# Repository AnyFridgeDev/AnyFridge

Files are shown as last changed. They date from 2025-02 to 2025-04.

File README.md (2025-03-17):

# AnyFridge

## GitHub
[GitHub](https://github.com/AnyFridgeDev/AnyFridge)

## Authors
- [Isaac Fletcher](https://github.com/isaac-fletcher)
- [Ethan Anderson](https://github.com/Elan456)
- [Caden Allen](https://github.com/coolguycaden)

## Project Overview

This is the development repository for AnyFridge, a compact device that brings smart features to any refrigerator. No need to buy the latest expensive model!
It is a WiFi-connected UPC barcode scanner that mounts magnetically to your fridge to make keeping track of your store purchases extremely convenient. Each item you scan will be cataloged in a web app that lets you view and manage your inventory levels.

## Organization

This repository is organized into the following sections:
    
    hardware/ - Stores system schematics and PCB for custom system hardware
        
        libraries/ - Stores custom libraries containing custom components in the schematics
    
    software/ - Contains custom firmware written for the ESP32
        
    webapp/ - Contains Python web app to handle inventory tracking management
    
    docs/ - Stores documentation about the project hardware and software

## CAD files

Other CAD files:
design/sleeve.blend

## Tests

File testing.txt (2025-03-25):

---Team Members---

Ethan Anderson (ema8@clemson.edu)
Isaac Fletcher (ifletch@clemson.edu)
Caden Allen (caden3@clemson.edu)

[GitHub](https://github.com/AnyFridgeDev/AnyFridge)

----AnyFridge Testing Guide---- 

Our tests are broken into two main categories
1. Onboard Software
2. Web App and Request Handling

Below our instructions and explanations for each test for each of the
two main categories.

---Onboard Software Tests---

For our onboard software, we use PlatformIO (PIO) to build and upload our code.
It's typically used as an extension for VS Code. 
To run our tests, you can use the CLI version which can be 
installed here: https://platformio.org/install 

--Test Barcode-- 

The barcode test ensures that we are able to scan UPC barcodes accurately.
The test starts by running a few unit test to ensure a good serial connection to
the barcode scanner. The test then enters a loop where it constantly scans and
prints any codes that are read to the serial monitor. 

Instructions:
1. Connect the barcode scanner using a breadboard
	(ESP32 pin) = (Scanner pin)
  	2 			= 	TX pin on scanner
  	3 			= 	RX pin on scanner
  	GND			= 	GND
  	3.3V 		= 	3.3V
2. cd into the software directory
	`cd software`
3. Run the test
	`pio test -f test_barcode`

--Test WiFi--

The WiFi test connects to a hard-coded WiFi network and then checks that
google.com can be pinged successfully.
It also tests sending a GET request to a custom domain of af.ethananderson.dev
where we have a server running to show what contents it receives. 
This test allows to check the WiFi functionality of the board. 

Instructions: 
1. cd into the software directory
	`cd software`
2. Edit the WiFi name and network passwords
	`vim test_wifi/test_wifi.cpp`
	Change `networkName` and `networkPswd` (smart phone hotspots work really well)
3. Run the test
	`pio test -f test_wifi`

--Test Access Point--

During the setup phase of the device, the user needs to be able to connect to
AnyFridge and give it network details to connect with.
The access point test puts the ESP32 into AP mode and then checks if 
it got an IP address.

Instructions:
1. cd into the software directory
	`cd software`
2. Run the test
	`pio test -f test_ap` 

If all the tests pass, it means the ESP32 went into AP mode and got an IP 
address on it's own local network. 

---Web App and Request Handling Tests---

Navigate to the `AnyFridge/webapp` folder.

The webapp processes code scans sent from the AnyFridge device. 
The webapp updates each user's list of scanned items based on the code 
and user id sent by the AnyFridge device. 

--Download Depdencies--

Before running the webapp, we'll need to install some Python packages. 

`cd webapp`
`pip install -r requirements.txt `

--Test Request Handling--

The AnyFridge device will send requests to the request handling server,
so we wrote tests that emulate each of these requests to ensure our server
handles them properly.

We check two main endpoints:
1. /api/update
Should change the list of scanned codes for the provided user.

2. /api/get/<userid>
Should return a list of all scanned codes for the provided user.

The test uses a FastAPI's built-in TestClient to simulate the request and
their handling. 

Instructions:
1. Run the command: `python -m unittest tests/test_request_handling.py`

If all the tests pass, it means the server succesfully updated and then 
later collected the expected scan lists for each user. 

--Local cURL + frontend check--

Another test involves hosting the webapp locally, sending a POST request to it 
and then viewing the website to ensure the scan list was updated properly. 

Instructions:
1. cd into the `AnyFridge/webapp` directory 
2. Run the curl command with `sh tests/local_curl_check.sh <userid>`
	Put whatever you like for the userid.
3. View the website and see if Frosted brown sugar cinnamon pastries 
are shown in the list. 

If everything worked, you'll also see a json file created inside of the 
`AnyFridge/webapp/data` folder named <userid>.json. It should contain the
upc code of the pastries. 

---Integration Test--
Navigate to the `AnyFridge/` folder.

--Test System Integration--
A sample program has been provided to test the scanning, WiFi, and web request
components of the device. It is to be used in conjunction with the 
request handler and gradio test ui to confirm that codes are being appropriately 
scanned and sent over the network.

Instructions:
1. Edit the WiFi name, network passwords, and host address
	`vim software/test/test_integration/test_integration.cpp`
	Change `networkName` and `networkPswd` (smart phone hotspots work really well)
    Change `host` to point to designated machine on the same network that will
	serve request handler and UI. You'll need to get the ip address of this machine
	on your hotspot network. 
2. cd into the webapp directory: `cd webapp`
3. Start the request handler on designated machine: `python request_handler.py`
4. Open another terminal 
4. Start the gradio debugging UI on designated machine: `gradio gradio_ui.py`
5. Open another terminal 
5. cd into the software directory: `cd software`
4. Upload and run the code onto the AnyFridge device. 
	`pio test -f test_integration` 
5. Scan a UPC code with the barcode scanner within 10 seconds 
6. Open the following page and type in "test_user" as the user_id. 
	http://0.0.0.0:8080

If everthing is working, when you scan a UPC code, you'll see the 
code printed to the serial monitor and the item appear on the locally-hosted 
website.

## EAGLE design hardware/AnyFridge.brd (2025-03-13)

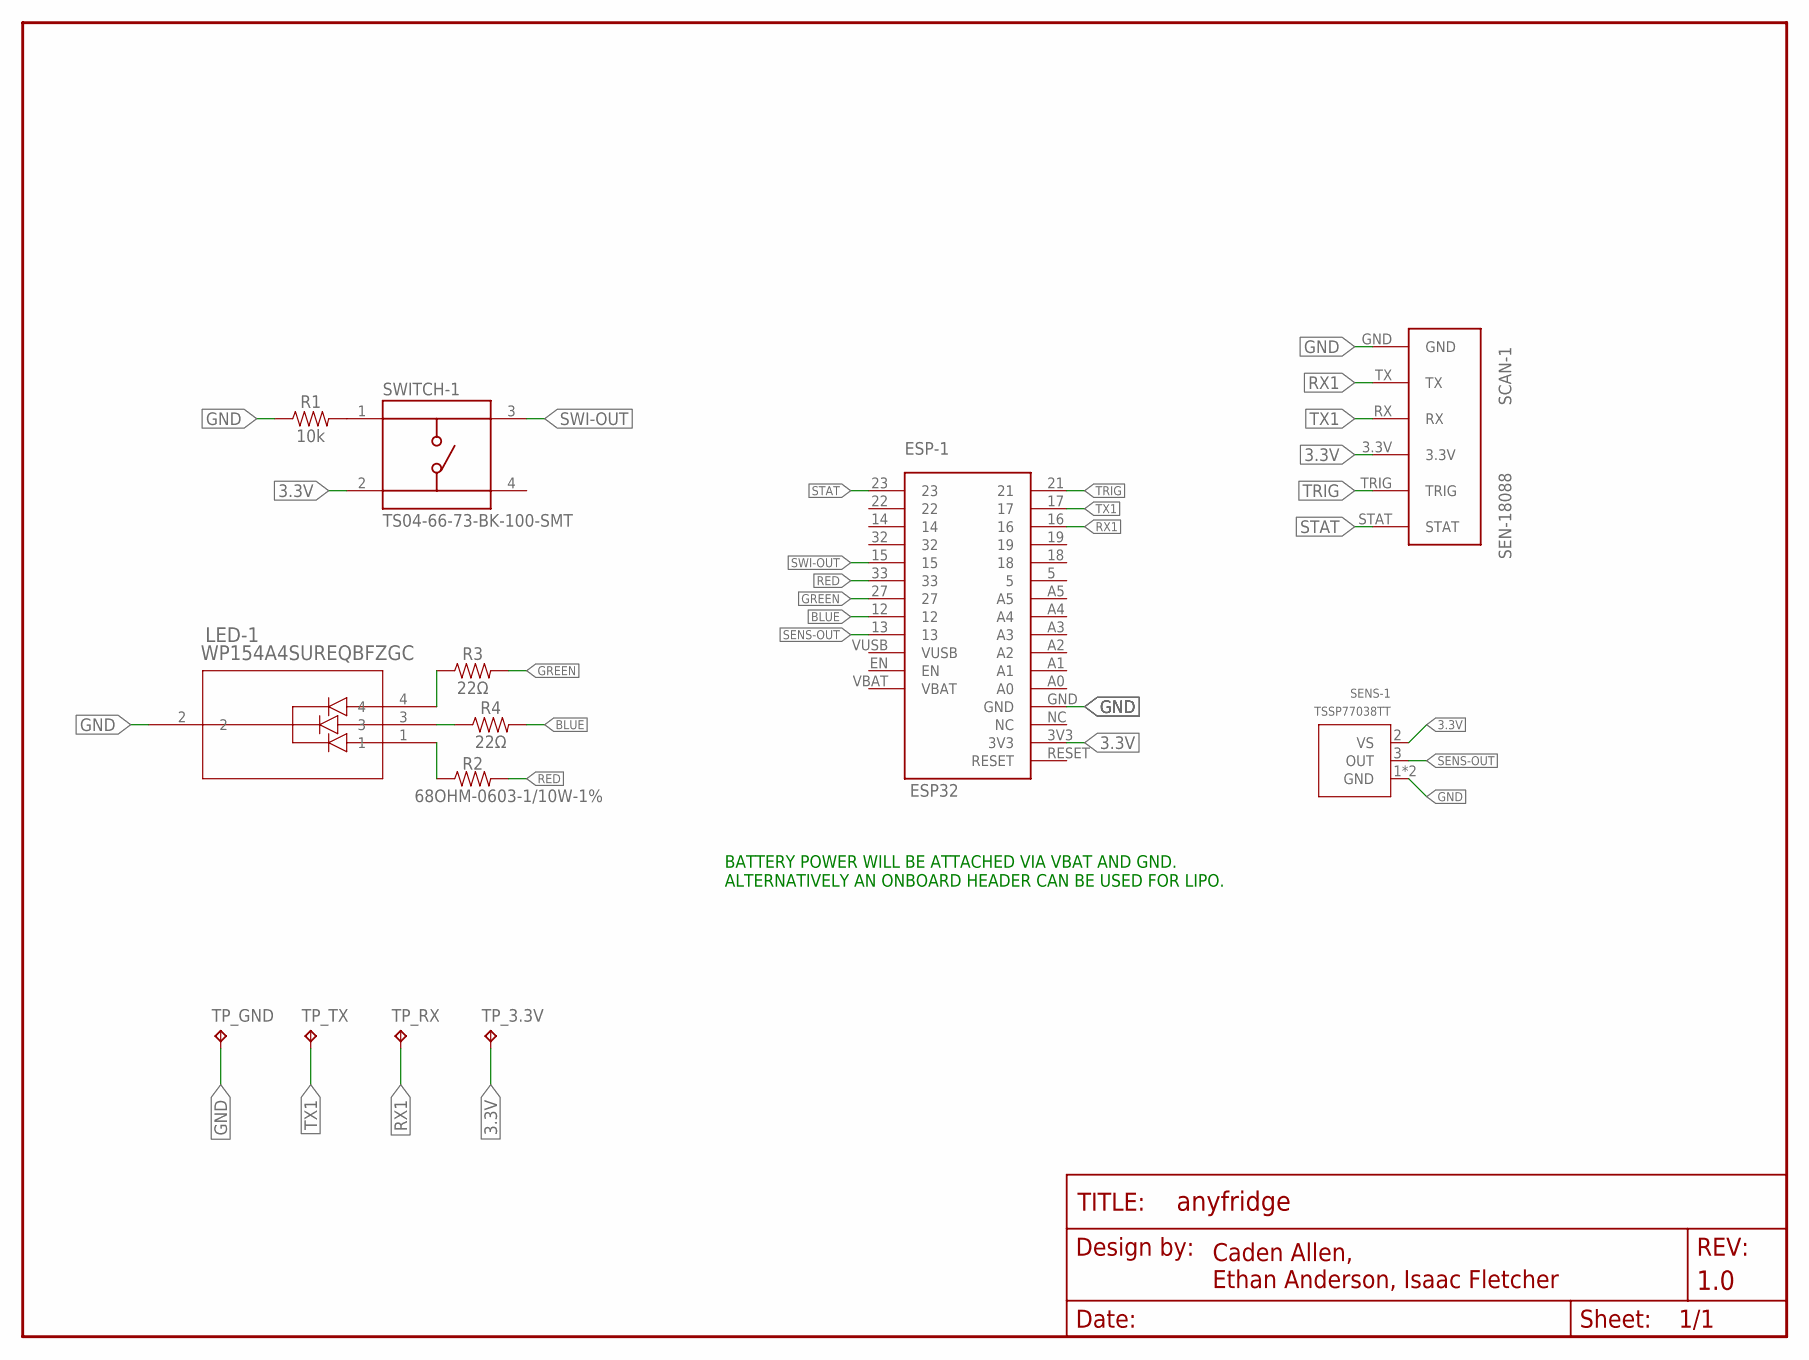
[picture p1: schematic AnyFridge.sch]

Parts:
ESP-1: ESP32
FRAME1: FRAME-LETTERNO_PACKAGE; DUMMY
LED-1: WP154A4SUREQBFZGC; LED4_WP154A4SUREQBFZGC_KNB
R1: 10k; AXIAL-0.3
R2: 68OHM-0603-1/10W-1%; 0603
R3, R4: 22Ω; 0603
SCAN-1: SEN-18088
SENS-1: TSSP77038TT
SWITCH-1: TS04-66-73-BK-100-SMT; SW_TS04-66-73-BK-100-SMT
TP_3.3V: TPPAD1-13; P1-13
TP_GND: TPPAD1-13; P1-13
TP_RX: TPPAD1-13; P1-13
TP_TX: TPPAD1-13; P1-13

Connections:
3.3V: ESP-1.3V3, SCAN-1.3.3V, SENS-1.2 (VS), SWITCH-1.2, TP_3.3V.TP
BLUE: ESP-1.12, R4.2
BLUE-IN: LED-1.3, R4.1
GND: ESP-1.GND, LED-1.2, R1.P$1 (1), SCAN-1.GND, SENS-1.1 (GND), SENS-1.4 (GND), TP_GND.TP
GREEN: ESP-1.27, R3.2
GREEN-IN: LED-1.4, R3.1
unnamed: R1.P$2 (2), SWITCH-1.1
RED: ESP-1.33, R2.2
RED-IN: LED-1.1, R2.1
RX1: ESP-1.16, SCAN-1.TX, TP_RX.TP
SENS-OUT: ESP-1.13, SENS-1.3 (OUT)
STAT: ESP-1.23, SCAN-1.STAT
SWI-OUT: ESP-1.15, SWITCH-1.3
TRIG: ESP-1.21, SCAN-1.TRIG
TX1: ESP-1.17, SCAN-1.RX, TP_TX.TP

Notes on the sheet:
BATTERY POWER WILL BE ATTACHED VIA VBAT AND GND. ALTERNATIVELY AN ONBOARD HEADER CAN BE USED FOR LIPO.

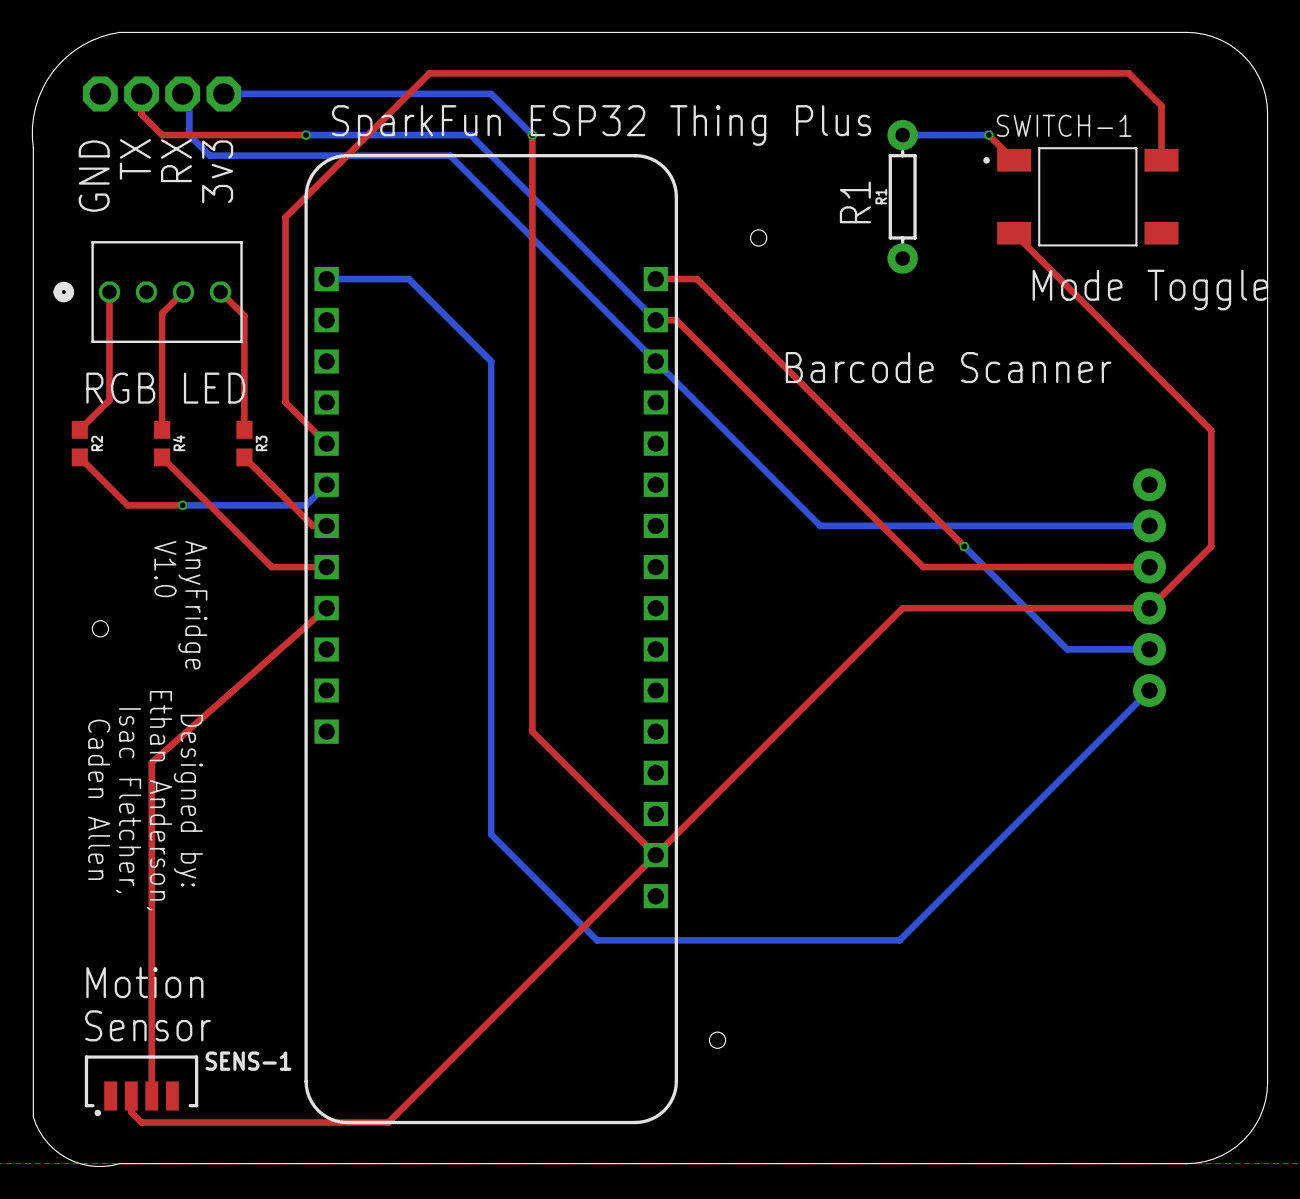
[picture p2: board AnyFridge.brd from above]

Board: 2 copper layers, 76.3 x 70.0 mm, 14 parts (1 on the bottom side), 15 nets.

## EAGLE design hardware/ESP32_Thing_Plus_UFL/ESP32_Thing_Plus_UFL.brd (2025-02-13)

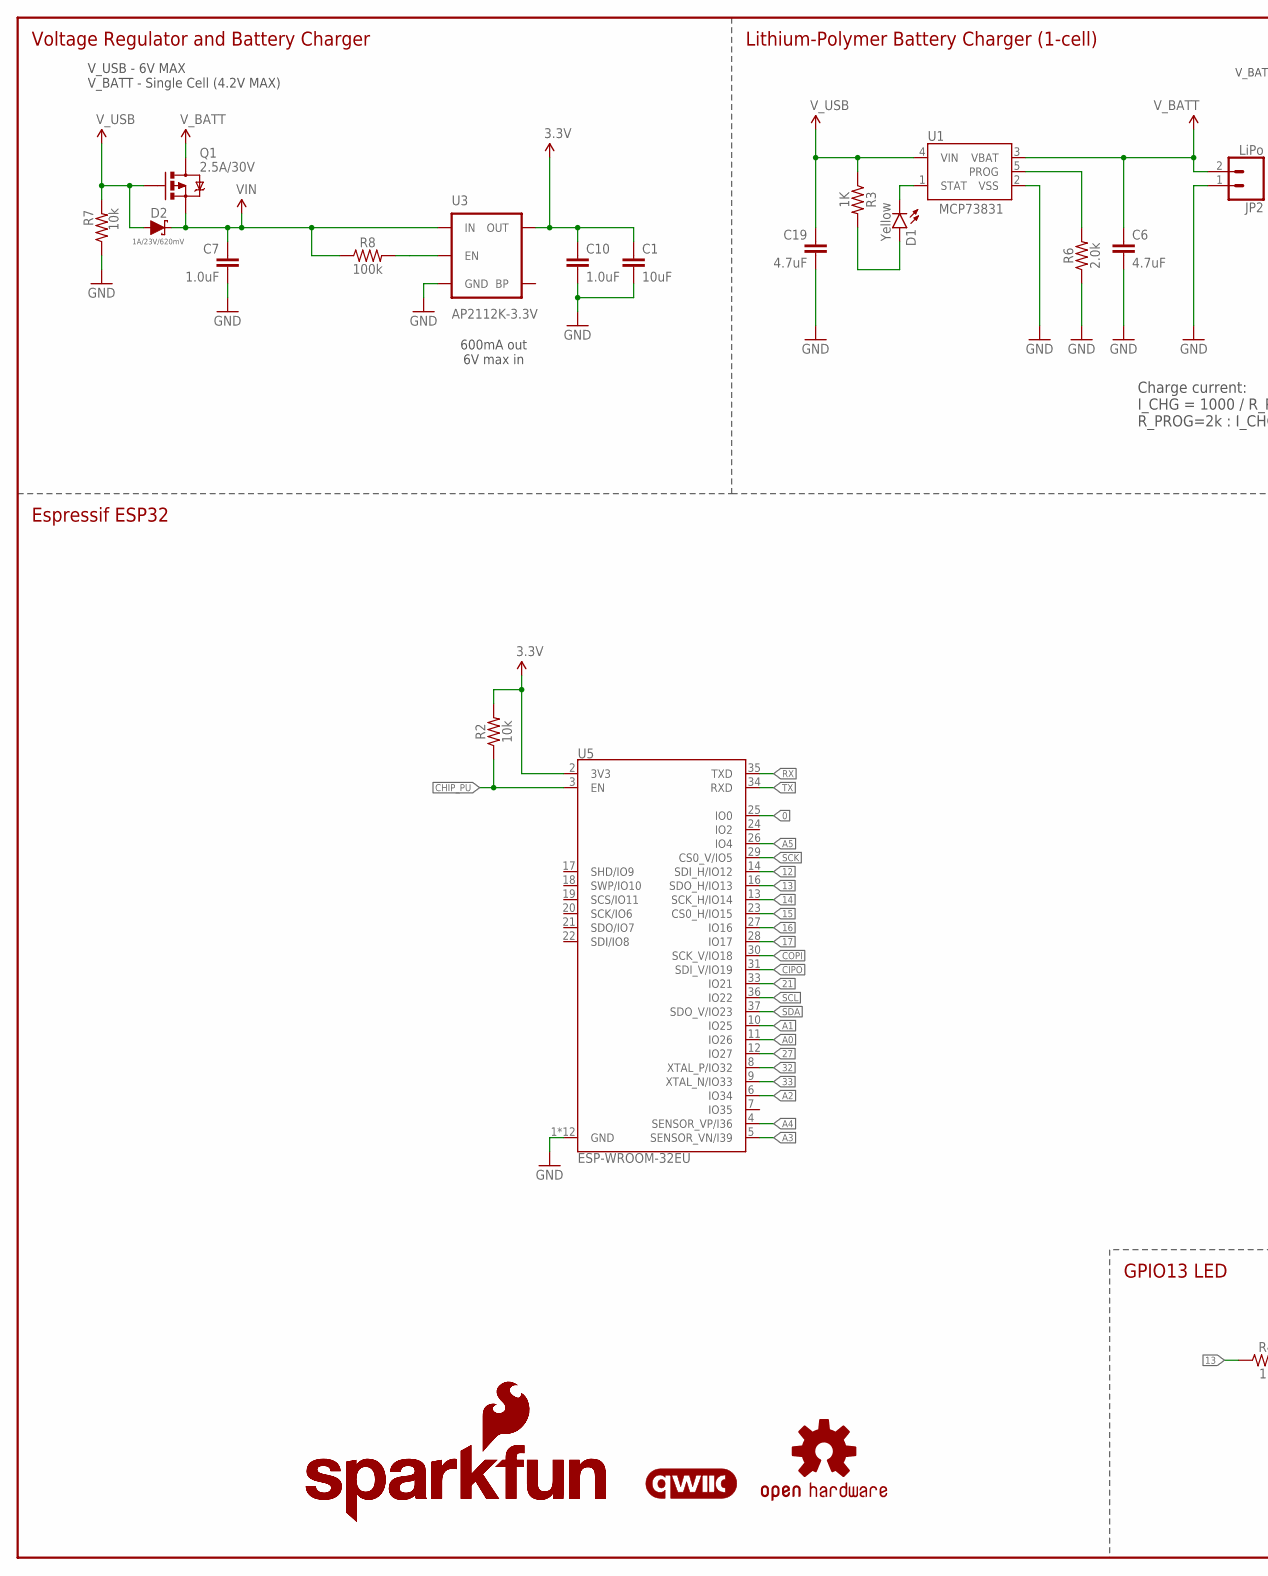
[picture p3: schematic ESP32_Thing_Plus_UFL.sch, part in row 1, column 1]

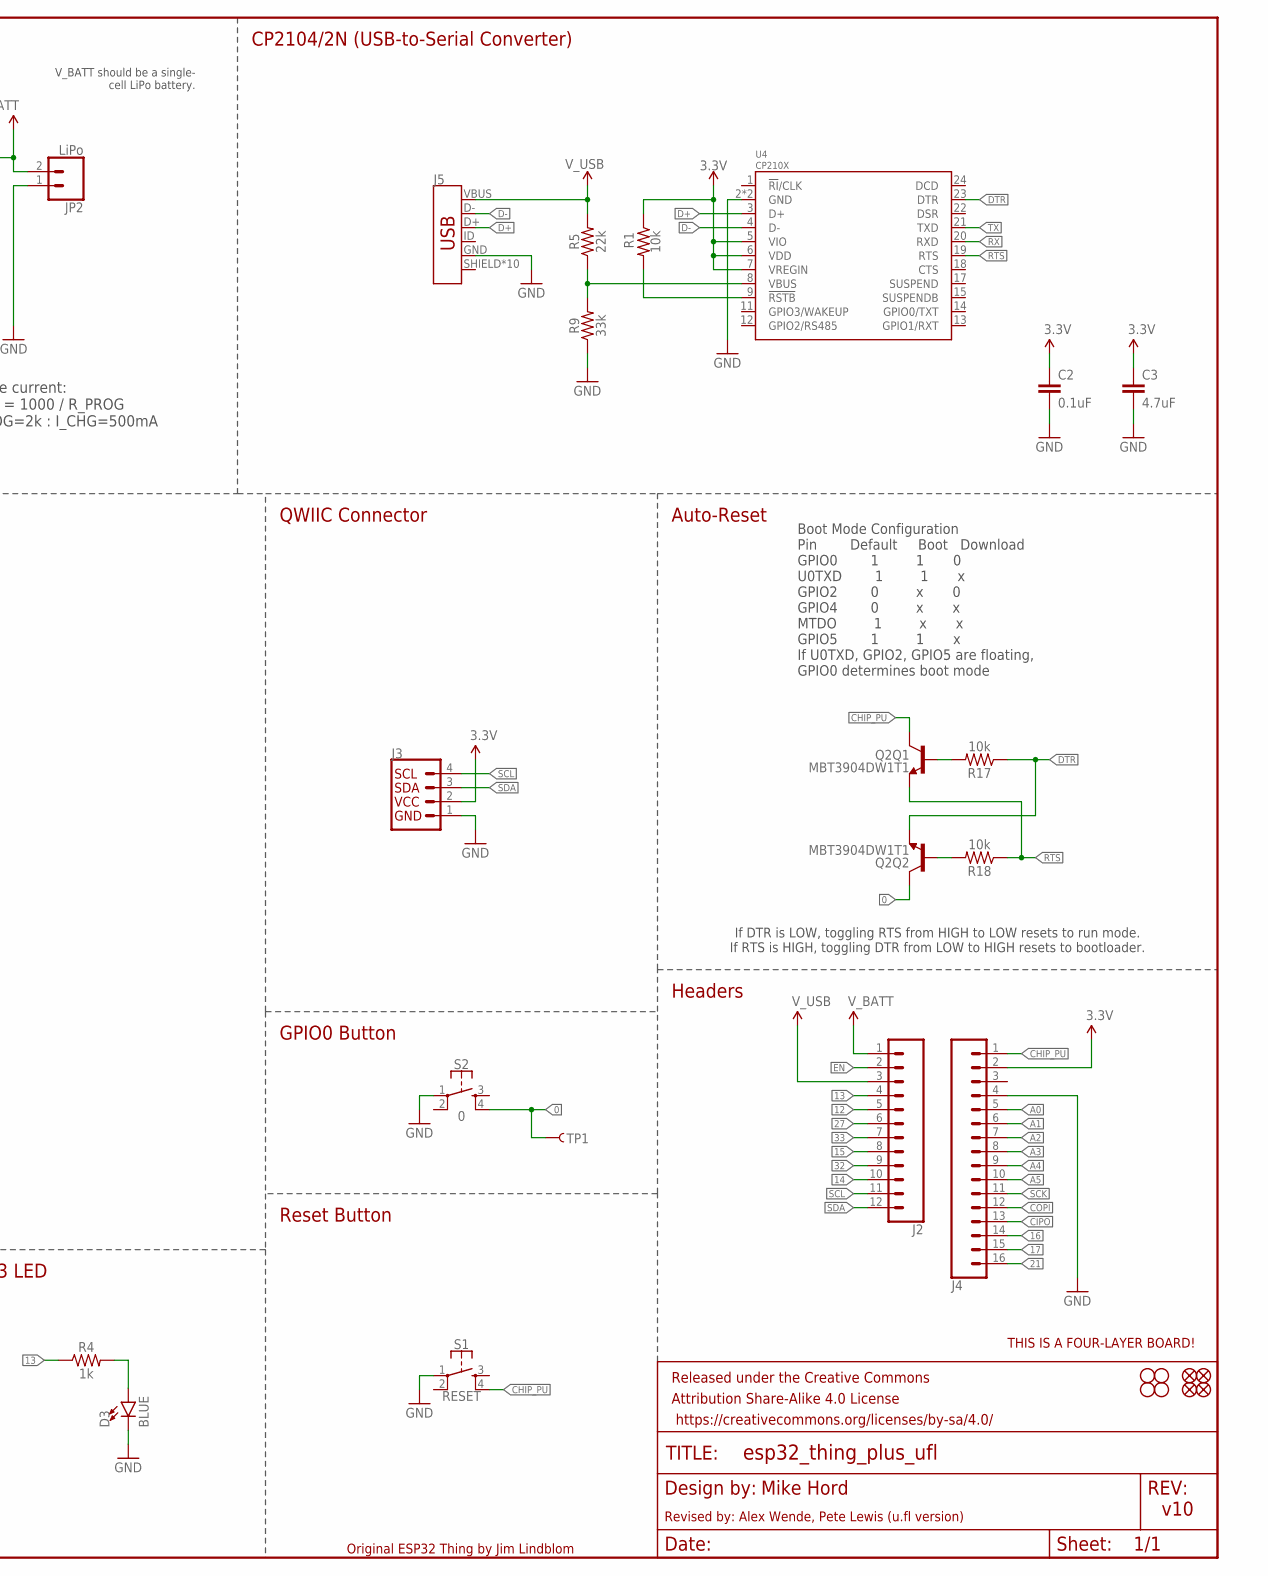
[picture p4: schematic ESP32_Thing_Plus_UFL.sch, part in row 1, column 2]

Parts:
C1: 10uF; 0603
C2: 0.1uF; 0402-TIGHT
C3, C6, C19: 4.7uF; 0402-TIGHT
C7, C10: 1.0uF; 0402-TIGHT
D1: Yellow; LED-0603
D2: 1A/23V/620mV; SOD-323
D3: BLUE; LED-0603
FD1, FD2, FD3, FD4: FIDUCIALUFIDUCIAL; FIDUCIAL-MICRO
FRAME1: FRAME-LEDGER; CREATIVE_COMMONS
H1, H2, H3, H4: STAND-OFFTIGHT; STAND-OFF-TIGHT
J2: CONN_12SM_SQ_NO_SILK; 1X12_SM_SQ_NOSILK
J3: QWIIC_CONNECTORJS-1MM; 1X04_1MM_RA
J4: CONN_161X16_SM_SQ_NOSILK; 1X16_SM_SQ_NOSILK
J5: USB_MICRO-B_HALF_PTH_MILL; USB-MICROB-PTH-MILL
JP2: LiPo; JST-2-SMD
LOGO2: OSHW-LOGOMINI; OSHW-LOGO-MINI
LOGO3, LOGO5: SFE_LOGO_NAME_FLAME.1_INCH; SFE_LOGO_NAME_FLAME_.1
LOGO4: FOUR_LAYER_WARNING
LOGO6: QWIIC_LOGO_5MM; QWIIC_5MM
Q1: 2.5A/30V; SOT23-3@1
Q2: MBT3904DW1T1; SC70-6
R1, R2, R7, R17, R18: 10k; 0603
R3: 1K; 0603
R4: 1k; 0603
R5: 22k; 0402-TIGHT
R6: 2.0k; 0603
R8: 100k; 0402-TIGHT
R9: 33k; 0402-TIGHT
S1: RESET; TACTILE_SWITCH_SMD_4.6X2.8MM
S2: 0; TACTILE_SWITCH_SMD_4.6X2.8MM
TP1: TEST-POINTTP_15TH_THRU; TP_15TH
U1: MCP73831; SOT23-5
U3: AP2112K-3.3V; SOT23-5
U4: CP210X; QFN24
U5: ESP-WROOM-32EU; ESP-WROOM-32EU-NARROW

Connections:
0: Q2.6 (C), S2.4, TP1.P$1, U5.25 (IO0)
3.3V: C1.1, C2.1, C3.1, C10.1, J3.2, J4.2, R1.1, R2.2, U3.5 (OUT), U4.5 (VIO), U4.6 (VDD), U4.7 (VREGIN), U5.2 (3V3)
12: J2.5, U5.14 (SDI_H/IO12)
13: J2.4, R4.1, U5.16 (SDO_H/IO13)
14: J2.10, U5.13 (SCK_H/IO14)
15: J2.8, U5.23 (CS0_H/IO15)
16: J4.14, U5.27 (IO16)
17: J4.15, U5.28 (IO17)
21: J4.16, U5.33 (IO21)
27: J2.6, U5.12 (IO27)
32: J2.9, U5.8 (XTAL_P/IO32)
33: J2.7, U5.9 (XTAL_N/IO33)
A0: J4.5, U5.11 (IO26)
A1: J4.6, U5.10 (IO25)
A2: J4.7, U5.6 (IO34)
A3: J4.8, U5.5 (SENSOR_VN/I39)
A4: J4.9, U5.4 (SENSOR_VP/I36)
A5: J4.10, U5.26 (IO4)
CHG: D1.C, U1.1 (STAT)
CHIP_PU: J4.1, Q2.3 (C), R2.1, S1.4, U5.3 (EN)
CIPO: J4.13, U5.31 (SDI_V/IO19)
COPI: J4.12, U5.30 (SCK_V/IO18)
D+: J5.D+, U4.3 (D+)
D-: J5.D-, U4.4 (D-)
DTR: Q2.1 (E), R17.1, U4.23 (DTR)
EN: J2.2, R8.2, U3.3 (EN)
GND: C1.2, C2.2, C3.2, C6.2, C7.2, C10.2, C19.2, D3.C, J3.1, J4.4, J5.GND, JP2.1 (2), R6.1, R7.1, R9.1, S1.1, S2.1, U1.2 (VSS), U3.2 (GND), U4.2 (GND), U4.PAD (GND), U5.1 (GND), U5.15 (GND), U5.38 (GND), U5.GND, U5.P$1 (GND), U5.P$2 (GND), U5.P$3 (GND), U5.P$4 (GND), U5.P$5 (GND), U5.P$6 (GND), U5.P$7 (GND), U5.P$8 (GND)
unnamed: R1.2, U4.9 (!RSTB)
unnamed: D3.A, R4.2
unnamed: R5.1, R9.2, U4.8 (VBUS)
unnamed: Q2.5 (B), R17.2
unnamed: Q2.2 (B), R18.2
unnamed: R6.2, U1.5 (PROG)
unnamed: D1.A, R3.2
RTS: Q2.4 (E), R18.1, U4.19 (RTS)
RX: U4.20 (RXD), U5.35 (TXD)
SCK: J4.11, U5.29 (CS0_V/IO5)
SCL: J2.11, J3.4, U5.36 (IO22)
SDA: J2.12, J3.3, U5.37 (SDO_V/IO23)
TX: U4.21 (TXD), U5.34 (RXD)
VIN: C7.1, D2.C, Q1.2 (S), R8.1, U3.1 (IN)
V_BATT: C6.1, J2.1, JP2.2 (1), Q1.3 (D), U1.3 (VBAT)
V_USB: C19.1, D2.A, J2.3, J5.VBUS, Q1.1 (G), R3.1, R5.2, R7.2, U1.4 (VIN)

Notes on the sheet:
Boot Mode Configuration Pin Default Boot Download GPIO0 1 1 0 U0TXD 1 1 x GPIO2 0 x 0 GPIO4 0 x x MTDO 1 x x GPIO5 1 1 x If U0TXD, GPIO2, GPIO5 are floating, GPIO0 determines boot mode
CP2104/2N (USB-to-Serial Converter)
V_BATT should be a single- cell LiPo battery.
Charge current: I_CHG = 1000 / R_PROG R_PROG=2k : I_CHG=500mA
Voltage Regulator and Battery Charger
Lithium-Polymer Battery Charger (1-cell)
600mA out 6V max in
Auto-Reset
Espressif ESP32
Reset Button
Headers
v10
Original ESP32 Thing by Jim Lindblom
If DTR is LOW, toggling RTS from HIGH to LOW resets to run mode. If RTS is HIGH, toggling DTR from LOW to HIGH resets to bootloader.
QWIIC Connector
Mike Hord
GPIO13 LED
GPIO0 Button
Revised by: Alex Wende, Pete Lewis (u.fl version)
V_USB - 6V MAX V_BATT - Single Cell (4.2V MAX)

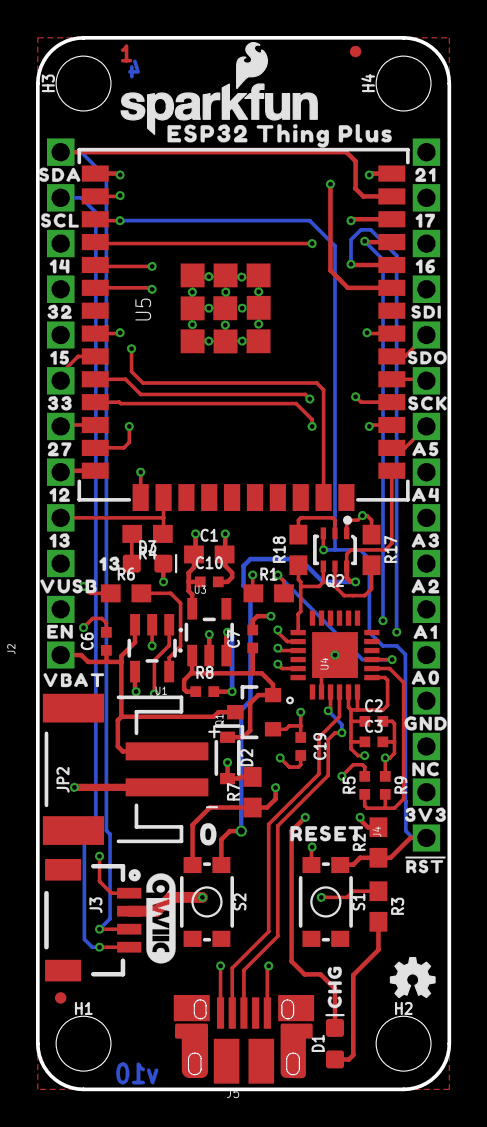
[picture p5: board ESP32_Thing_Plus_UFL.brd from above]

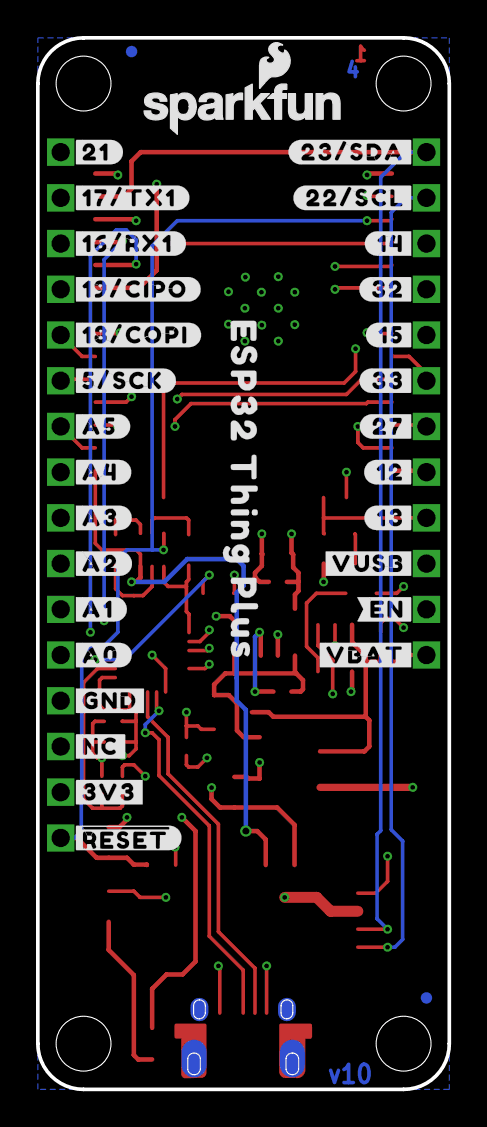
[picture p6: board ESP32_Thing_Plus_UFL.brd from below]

Board: 4 copper layers, 22.9 x 58.4 mm, 112 parts (32 on the bottom side), 43 nets.

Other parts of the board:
U$1: ESP32_THING_PLUS_0
U$2: SDI0
U$3: #21#0
U$4: #17#TX1#0
U$5: #16#RX1#0
U$6: SDO0
U$7: #RST#0
U$8: #19#CIPO#0
U$10: #18#COPI#0
U$11: #5#SCK#0
U$12: #A5#0
U$19: #A4#0
U$21: #A3#0
U$22: #A2#0
U$24: ESP32_THING_PLUS0
U$25: SDA0
U$26: SCL0
U$27: #A1#0
U$28: #A0#0
U$31: #23#SDA#0
U$32: #GND#0
U$33: #22#SCL#0
U$34: #14#0
U$35: #32#0
U$36: #15#0
U$37: #33#0
U$38: #27#0
U$39: #12#0
U$40: #13#0
U$41: #VUSB#0
U$42: #VBAT#0
U$43: #EN#0
U$44: #NC#0
U$45: #3V3#0
U$46: ##RESET##0
U$58: 140
U$59: ORDERING_INSTRUCTIONS
U$68: 320
U$69: 150
U$70: 330
U$71: 270
U$72: 120
U$73, U$74: 130
U$75: VUSB0
U$76: EN0
U$77: VBAT0
U$78: CHG0
U$79: RESET0
U$81: 3V30
U$82: NC0
U$83: GND0
U$84: A00
U$85: A10
U$86: A20
U$87: A30
U$88: A40
U$89: A50
U$90: SCK0
U$93: 160
U$94: 170
U$95: 210
U$96: 00

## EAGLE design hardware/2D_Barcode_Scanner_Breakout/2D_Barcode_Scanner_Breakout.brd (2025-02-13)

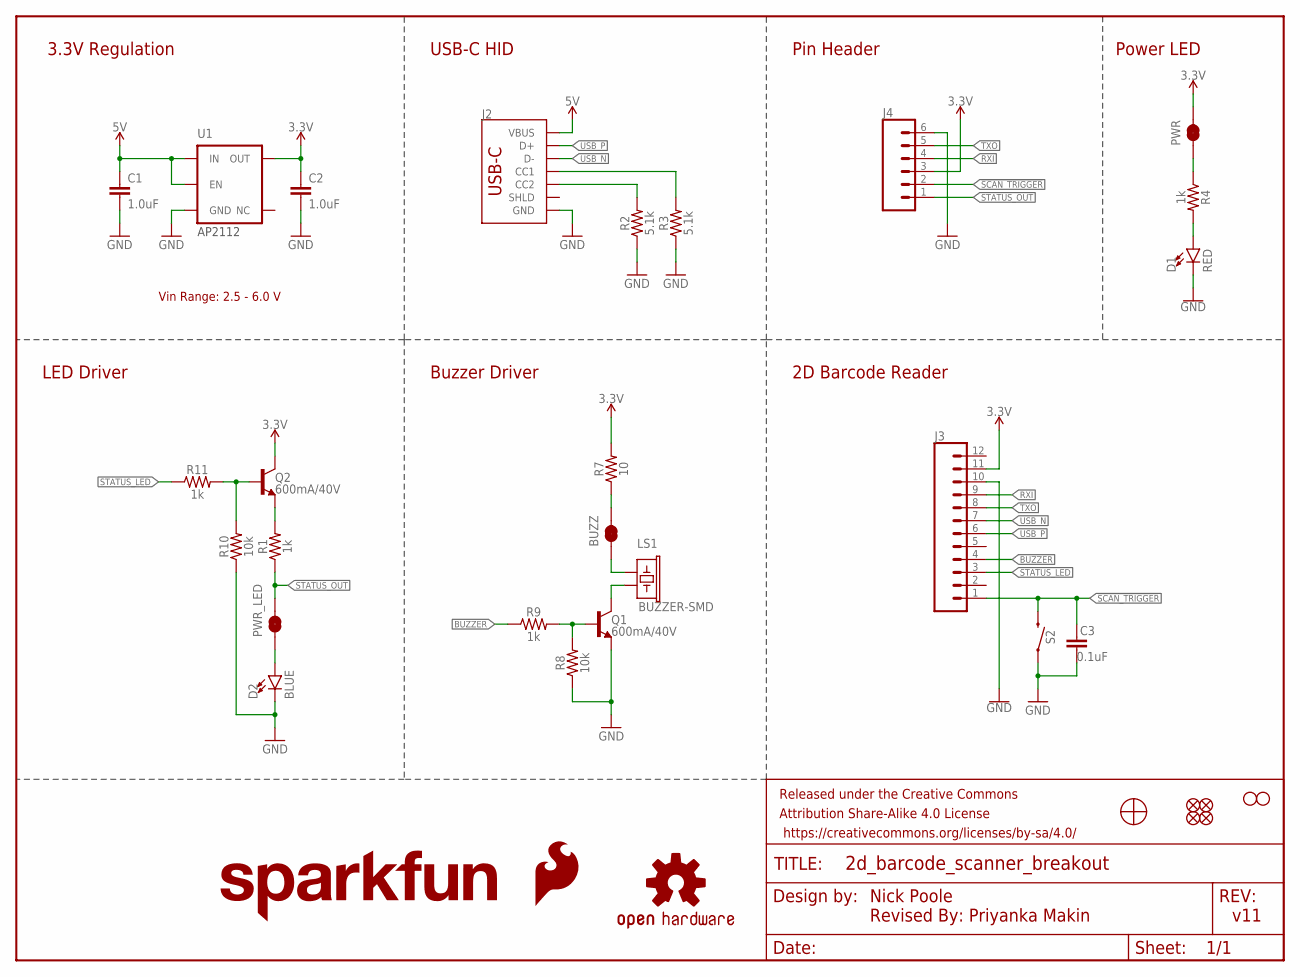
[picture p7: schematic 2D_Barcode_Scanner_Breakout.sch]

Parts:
BUZZ: JUMPER-SMT_2_NC_TRACE_SILK; SMT-JUMPER_2_NC_TRACE_SILK
C1, C2: 1.0uF; 0603
C3: 0.1uF; 0603
D1: RED; LED-0603
D2: BLUE; LED-0603
FD1, FD2, FD3, FD4: FIDUCIALUFIDUCIAL; FIDUCIAL-MICRO
FRAME1: FRAME-LETTER; CREATIVE_COMMONS
H2, H3: STAND-OFF
J2: USB_C_2-LAYER_PADS; USB-C-16P-2LAYER-PADS
J3: CONN_12FPC_12_0.5MM; FPC_12_0.5MM
J4: CONN_06NO_SILK_FEMALE_PTH; 1X06_NO_SILK
LOGO1: OSHW-LOGOS; OSHW-LOGO-S
LOGO2: SFE_LOGO_FLAME.1_INCH; SFE_LOGO_FLAME_.1
LOGO3: SFE_LOGO_NAME.1_INCH; SFE_LOGO_NAME_.1
LS1: BUZZER-SMD; BUZZER-CCV
PWR: JUMPER-SMT_2_NC_TRACE_SILK; SMT-JUMPER_2_NC_TRACE_SILK
PWR_LED: JUMPER-SMT_2_NC_TRACE_SILK; SMT-JUMPER_2_NC_TRACE_SILK
Q1, Q2: 600mA/40V; SOT23-3
R1, R4, R9, R11: 1k; 0603
R2, R3: 5.1k; 0603
R7: 10; 0603
R8, R10: 10k; 0603
S2: MOMENTARY-SWITCH-SPST-SMD-5.2MM-TALL; TACTILE_SWITCH_SMD_5.2MM
U1: 3.3V; SOT23-5
U2: BARCODE_SCANNER_MOUNT

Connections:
3.3V: C2.1, J3.11, J4.3, PWR.2, Q2.3 (C), R7.2, U1.5 (OUT)
5V: C1.1, J2.VBUS1 (VBUS), J2.VBUS2 (VBUS), U1.1 (IN), U1.3 (EN)
!SCAN_TRIGGER!: C3.1, J3.1, J4.2, S2.3 (2)
BUZZER: J3.4, R9.1
CC3: J2.A5 (CC1), R3.2
CC4: J2.B5 (CC2), R2.2
GND: C1.2, C2.2, C3.2, D1.C, D2.C, J2.GND, J2.GND2 (GND), J3.10, J4.6, Q1.2 (E), R2.1, R3.1, R8.1, R10.1, S2.1, U1.2 (GND)
unnamed: BUZZ.2, R7.1
unnamed: LS1.- (2), Q1.3 (C)
unnamed: BUZZ.1, LS1.+ (1)
unnamed: Q2.2 (E), R1.2
unnamed: Q1.1 (B), R8.2, R9.2
unnamed: PWR.1, R4.1
unnamed: Q2.1 (B), R10.2, R11.2
unnamed: D2.A, PWR_LED.1
unnamed: D1.A, R4.2
RXI: J3.9, J4.4
STATUS_LED: J3.3, R11.1
STATUS_OUT: J4.1, PWR_LED.2, R1.1
TXO: J3.8, J4.5
USB_N: J2.A7 (D-), J2.B7 (D-), J3.7
USB_P: J2.A6 (D+), J2.B6 (D+), J3.6

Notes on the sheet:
3.3V Regulation
AP2112
Pin Header
2D Barcode Reader
LED Driver
Buzzer Driver
USB-C HID
Power LED
Nick Poole Revised By: Priyanka Makin
v11
Vin Range: 2.5 - 6.0 V

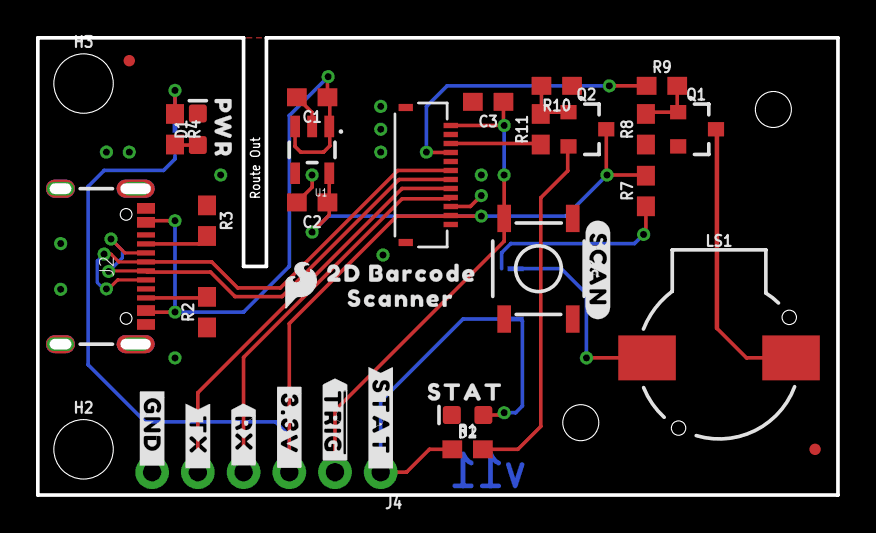
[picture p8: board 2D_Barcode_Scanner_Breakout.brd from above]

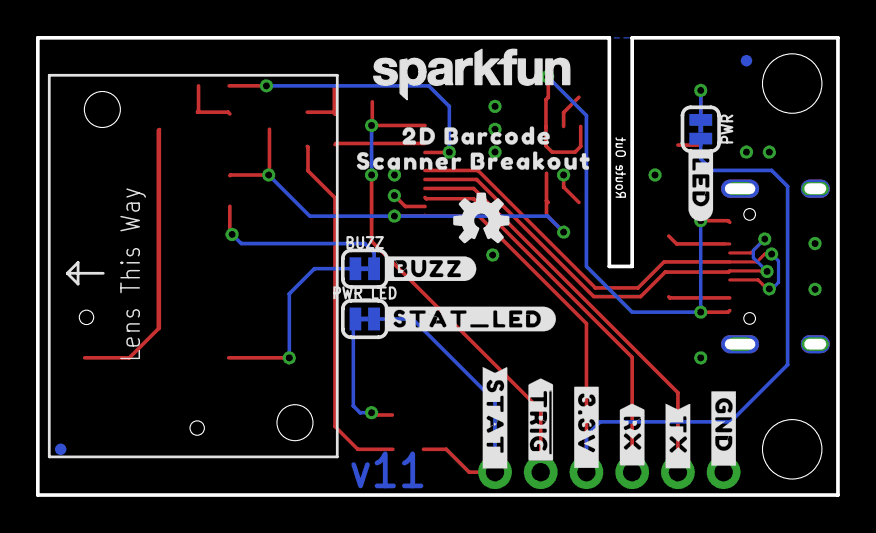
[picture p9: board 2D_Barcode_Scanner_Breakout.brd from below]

Board: 2 copper layers, 44.5 x 25.4 mm, 58 parts (19 on the bottom side), 22 nets.

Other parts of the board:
U$1, U$7: ##TRIG##0
U$2, U$21: #STAT_#0
U$3: STAT0
U$4: #SCAN#0
U$5: #BUZZ#0
U$6: #STAT_LED#0
U$8: PWR0
U$9: #LED#0
U$17, U$18: 2D_BARCODE0
U$19: SCANNER0
U$20: SCANNER_BREAKOUT0
U$26, U$27: #TX_#0
U$28, U$29: #3#3V_#0
U$30, U$31: #RX_#0
U$32, U$33: #GND_#0

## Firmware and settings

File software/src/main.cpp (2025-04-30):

/*
  By: AnyFridge Team
  Term: Spring 2025 

  References:
  - POST example from https://github.com/espressif/arduino-esp32/blob/master/libraries/HTTPClient/examples/BasicHttpsClient/BasicHttpsClient.ino
  - ISR from https://lastminuteengineers.com/handling-esp32-gpio-interrupts-tutorial/
  - NetWizard example from https://docs.netwizard.pro/docs/intro/example
*/

    #include <Arduino.h>
    #include <ArduinoJson.h>
    #include <HTTPClient.h>
    #include <WiFiClientSecure.h>
    #include <NetWizard.h>
    #include <WebServer.h>
    #include <Preferences.h>

// This is a Google Trust Services cert, the root Certificate Authority that
// signed the server certificate for the demo server https://jigsaw.w3.org in this
// example. This certificate is valid until Jan 28 00:00:42 2028 GMT
const char *rootCACertificate = R"string_literal(
-----BEGIN CERTIFICATE-----
MIIDejCCAmKgAwIBAgIQf+UwvzMTQ77dghYQST2KGzANBgkqhkiG9w0BAQsFADBX
MQswCQYDVQQGEwJCRTEZMBcGA1UEChMQR2xvYmFsU2lnbiBudi1zYTEQMA4GA1UE
CxMHUm9vdCBDQTEbMBkGA1UEAxMSR2xvYmFsU2lnbiBSb290IENBMB4XDTIzMTEx
NTAzNDMyMVoXDTI4MDEyODAwMDA0MlowRzELMAkGA1UEBhMCVVMxIjAgBgNVBAoT
GUdvb2dsZSBUcnVzdCBTZXJ2aWNlcyBMTEMxFDASBgNVBAMTC0dUUyBSb290IFI0
MHYwEAYHKoZIzj0CAQYFK4EEACIDYgAE83Rzp2iLYK5DuDXFgTB7S0md+8Fhzube
Rr1r1WEYNa5A3XP3iZEwWus87oV8okB2O6nGuEfYKueSkWpz6bFyOZ8pn6KY019e
WIZlD6GEZQbR3IvJx3PIjGov5cSr0R2Ko4H/MIH8MA4GA1UdDwEB/wQEAwIBhjAd
BgNVHSUEFjAUBggrBgEFBQcDAQYIKwYBBQUHAwIwDwYDVR0TAQH/BAUwAwEB/zAd
BgNVHQ4EFgQUgEzW63T/STaj1dj8tT7FavCUHYwwHwYDVR0jBBgwFoAUYHtmGkUN
l8qJUC99BM00qP/8/UswNgYIKwYBBQUHAQEEKjAoMCYGCCsGAQUFBzAChhpodHRw
Oi8vaS5wa2kuZ29vZy9nc3IxLmNydDAtBgNVHR8EJjAkMCKgIKAehhxodHRwOi8v
Yy5wa2kuZ29vZy9yL2dzcjEuY3JsMBMGA1UdIAQMMAowCAYGZ4EMAQIBMA0GCSqG
SIb3DQEBCwUAA4IBAQAYQrsPBtYDh5bjP2OBDwmkoWhIDDkic574y04tfzHpn+cJ
odI2D4SseesQ6bDrarZ7C30ddLibZatoKiws3UL9xnELz4ct92vID24FfVbiI1hY
+SW6FoVHkNeWIP0GCbaM4C6uVdF5dTUsMVs/ZbzNnIdCp5Gxmx5ejvEau8otR/Cs
kGN+hr/W5GvT1tMBjgWKZ1i4//emhA1JG1BbPzoLJQvyEotc03lXjTaCzv8mEbep
8RqZ7a2CPsgRbuvTPBwcOMBBmuFeU88+FSBX6+7iP0il8b4Z0QFqIwwMHfs/L6K1
vepuoxtGzi4CZ68zJpiq1UvSqTbFJjtbD4seiMHl
-----END CERTIFICATE-----
)string_literal";

#include "HardwareSerial.h"
HardwareSerial barcodeSerial(1); // UART BUS 1

#include "SparkFun_DE2120_Arduino_Library.h" 
DE2120 scanner;

#define BUFFER_LEN 40
char scanBuffer[BUFFER_LEN] = {0};

// --- Configuration for AnyFridge endpoint ---
const char *host        = "https://af.ethananderson.dev/api/update";
String user             = "";

// -- Preferences for storing user ID --
Preferences prefs;

// --- NetWizard Configuration ---
WebServer server(80);
NetWizard NW(&server);
NetWizardParameter nw_header(&NW, NW_HEADER, "User Configuration");
NetWizardParameter nw_divider1(&NW, NW_DIVIDER);
NetWizardParameter nw_user_id_input(&NW, NW_INPUT, "User ID", "", "isaac"); 

// --- Network Communication ---
WiFiClientSecure *client = nullptr;
HTTPClient https;
uint32_t lastScanTime_ms = 0;
#define DISCONNECT_TIMEOUT_MS 10000 // After 10 seconds of no activity, disconnect from the server

enum mode {ADDITION, SUBTRACTION};
mode current_mode = ADDITION;

#define RED 33
#define GREEN 27
#define BLUE 12
#define BUTTON 15

unsigned long button_time = 0;
unsigned long last_button_time = 0;

void IRAM_ATTR button_isr() {

    button_time = millis();

    if (button_time - last_button_time > 250) {
        
        // Swap the current mode
        if (current_mode == ADDITION) {
            current_mode = SUBTRACTION;
            digitalWrite(RED, HIGH);
            digitalWrite(GREEN, LOW);
        } else {
            current_mode = ADDITION;
            digitalWrite(RED, LOW);
            digitalWrite(GREEN, HIGH);
        }
        last_button_time = button_time;
    }
    
}

bool connect_to_server(){
    client = new WiFiClientSecure();
    client->setCACert(rootCACertificate);
    bool connected = https.begin(*client, host);
    if (connected) {
        Serial.println("Connected to server");
    } else {
        Serial.println("Failed to connect to server");
    }
    return connected;
}

void setup()
{
    Serial.begin(115200);

    // Wait for USB seems to not work
    while (!Serial) {
        delay(100); // Wait for native USB
    }

    // Configure LEDS
    pinMode(RED, OUTPUT); // LED 1
    pinMode(GREEN, OUTPUT); // LED 2
    pinMode(BLUE, OUTPUT); // LED 3

    // Initialize scanner module
    while (!scanner.begin(barcodeSerial)){
        Serial.println("[-] Scanner not detected, retrying...");
        delay(1000);
    }

    Serial.println("[+] Scanner online!");

    scanner.lightOff();
    scanner.disableAll2D();
    scanner.reticleOn();
    scanner.stopScan();
    
    scanner.enableContinuousRead(1);
    scanner.enableMotionSense(50U);

    digitalWrite(BLUE, HIGH);
    digitalWrite(GREEN, LOW);
    digitalWrite(RED, LOW);

    // Try to load the current user ID from preferences
    prefs.begin("anyfridge", true);
    user = prefs.getString("user_id", "");
    prefs.end();

    // Check if we actually got a user ID
    if (user.length() == 0) {
        Serial.println("[-] No saved user ID found, setting to empty string");
    } else {
        Serial.print("[+] Saved User ID found: ");
        Serial.println(user);
    }

    // Resets NetWizard to default state
    // NW.reset();

    NW.setConnectTimeout(10000);
    NW.setStrategy(NetWizardStrategy::BLOCKING);
    NW.autoConnect("AnyFridge", "");

    Serial.println("[+] Connected to WiFi!");

    // If the netwizard provides a new user ID, save it
    if (nw_user_id_input.getValueStr() != "") {
        user = nw_user_id_input.getValueStr();
        Serial.print("[+] New User ID found from netwizard: ");
        Serial.println(user);
        prefs.begin("anyfridge", false);
        prefs.putString("user_id", user);
        prefs.end();
    } else {
        Serial.println("[-] No new User ID found");
    }

    digitalWrite(BLUE, LOW);
    digitalWrite(GREEN, HIGH);

    pinMode(BUTTON, INPUT_PULLDOWN);
    attachInterrupt(BUTTON, button_isr, FALLING);

    Serial.println("[+] AnyFridge ready!");

}

bool post_code(char *code)
{
    if (!https.connected()){
        Serial.println("[-] Not connected to server, trying to connect...");
        if (!connect_to_server()){
            Serial.println("[-] Failed to connect to server");
            return false;
        }
    }

    https.addHeader("Content-Type", "application/json");

    String payload;
    String action;

    noInterrupts();
    current_mode == ADDITION ? action = "POST" : action = "DELETE";
    interrupts();

    JsonDocument doc;
    doc["upc_code"] = String(code);
    doc["user_id"] = user;
    doc["action"] = action;
    serializeJson(doc, payload);

    int httpResponseCode = https.POST(payload);
    
    Serial.print(httpResponseCode);

    Serial.println();

    return true;
}

void loop()
{ 
    
    NW.loop();

    if (scanner.readBarcode(scanBuffer, BUFFER_LEN))
    {

        Serial.print("[+] Code found: ");
        Serial.println(String(scanBuffer));
        
        post_code(scanBuffer);

        // Flush scanBuffer and Serial line
        memset(scanBuffer, 0, BUFFER_LEN);
        while (barcodeSerial.available()) barcodeSerial.read();

        lastScanTime_ms = millis();

    }

}

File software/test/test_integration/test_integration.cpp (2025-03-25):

/*
  By: AnyFridge Team (some code sourced from hoshmandent - https://github.com/hoshmandent/POST-request-Arduino)
  Term: Spring 2025 
*/

#include <Arduino.h>
#include <ArduinoJson.h>
#include <unity.h>
#include <WiFi.h>
#include "HardwareSerial.h"
HardwareSerial barcodeSerial(1); // UART BUS 1

#include "SparkFun_DE2120_Arduino_Library.h" 
DE2120 scanner;

#define BUFFER_LEN 40
char scanBuffer[BUFFER_LEN];

// --- Replace these with your network credentials ---
const char *networkName = "iPhone";
const char *networkPswd = "password";

// --- Domain/Port for AnyFridge endpoint ---
const char *host        = "";
const int hostPort      = 5000;

void test_integration()
{   
    // attempt to scan a code for up to ten seconds
    unsigned long startTime = millis();
    while (millis() - startTime < 10000)
    {
        scanner.startScan();
        delay(500);

        if (scanner.readBarcode(scanBuffer, BUFFER_LEN))
        {
            Serial.print("Code found: ");
            Serial.print(String(scanBuffer));
            Serial.println();
            
            WiFiClient client;
            bool connected = client.connect(host, hostPort);
        
            TEST_ASSERT_TRUE_MESSAGE(
                connected,
                "Failed to connect to server (client.connect() returned false)."
            );

            // Define the URL and the payload of the POST request
            String endpoint = "/update";
            String user = "test_user";
            String payload;
            String action;

            JsonDocument doc;
            doc["upc_code"] = String(scanBuffer);
            doc["user_id"] = user;
            doc["action"] = action;
            serializeJson(doc, payload);

            String request = ("POST " + endpoint + " HTTP/1.1\r\n" +
                            "Host: " + host + "\r\n" +
                            "Content-Type: application/json\r\n" +
                            "Content-Length: " + payload.length() + "\r\n" +
                            "Connection: close\r\n\r\n" +
                            payload);

            // Send the POST request
            Serial.print(request);
            Serial.println();
            
            client.print(request);

            // Close the connection
            client.stop();
            return;
        }
        scanner.stopScan();
        delay(500);
    }
    
    TEST_ASSERT_NOT_NULL_MESSAGE(NULL, "The scanner timed out.");
    
}

void setup()
{
    Serial.begin(115200);

    // Wait for USB seems to not work
    while (!Serial) {
        delay(100); // Wait for native USB
    }

    // Initialize scanner module
    scanner.begin(barcodeSerial);

    // Intitialize WiFi connectivity
    WiFi.mode(WIFI_STA);
    WiFi.begin(networkName, networkPswd);
  
    // Wait until successful connection
    unsigned long startAttemptTime = millis();
    while (WiFi.status() != WL_CONNECTED)
    {
      delay(250);
    }

    // Assigned IP Address
    Serial.println(WiFi.localIP());

    // Extra 5-sec delay to allow the user to open the Serial Monitor
    delay(5000);

    // Initialize Unity:
    UNITY_BEGIN();

    // Run Tests:
    RUN_TEST(test_integration);

    // Finish Unity and do not rerun:
    UNITY_END();

}

void loop() {
    // Empty. Tests run once in setup().
}

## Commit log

2025-02-13 Added schematic files
    [2D_Barcode_Scanner_Breakout.brd, 2D_Barcode_Scanner_Breakout.sch, AnyFridge.sch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]
2025-02-13 hehe haha made sensor
    [sensor.sch]
2025-02-16 Added frame
    [AnyFridge.sch]
2025-02-16 Added ESP32 and custom frame libraries. Updated main schematic.
2025-02-19 Adjust hole positions and diameter on footprint based on sparkfun eagle files
2025-02-20 most of schematic finished
2025-02-20 Wire LED + Button, change UART
    [AnyFridge.brd, AnyFridge.sch]
2025-02-20 Updated schematic
    [AnyFridge.sch]
2025-02-20 Added schematic grouping
    [AnyFridge.sch]
2025-02-23 Updated ESP32 library to be accurately scaled
2025-02-24 updated board
    [AnyFridge.brd]
2025-02-24 Rotated barcode scanner
    [AnyFridge.brd]
2025-02-25 Add GND copper pour on top layer
    [AnyFridge.brd, AnyFridge.sch]
2025-02-26 Added comment to schematic
    [AnyFridge.sch]
2025-02-26 Increase traces to 16mm and add test points for UART
    [AnyFridge.brd, AnyFridge.sch]
2025-02-26 Make PCB much smaller
    [AnyFridge.brd]
2025-02-26 Add initial silkscreen
    [AnyFridge.brd]
2025-02-26 attempted fix for LED spacing
    [AnyFridge.brd, AnyFridge.sch]
2025-02-26 Updated board and schematic to use appropriate ESP library
    [AnyFridge.brd, AnyFridge.sch]
2025-02-27 Make traces to LED less wonky
    [AnyFridge.brd]
2025-02-27 Align all traces to 45deg angles
    [AnyFridge.brd]
2025-02-27 Removed sensor file
    [sensor.sch]
2025-02-27 Rounded corner
    [AnyFridge.brd]
2025-02-27 Minor updates.
    [AnyFridge.brd]
2025-02-27 Added 120 ohm resistor to board/schematic
    [AnyFridge.brd, AnyFridge.sch]
2025-02-27 schematic updated
    [AnyFridge.brd, AnyFridge.sch]
2025-02-27 Add Green and Blue resistors
    [AnyFridge.brd, AnyFridge.sch]
2025-02-27 Put project name + revision in silkscreen, rename resistor to LED pins
    [AnyFridge.brd, AnyFridge.sch]
2025-03-10 Fix TX + RX on Scanner LIB + Flip Scanner on AnyFridgeBRD
    [AnyFridge.brd, AnyFridge.sch]
2025-03-11 started on sleeve design
    [sleeve.blend]
2025-03-13 Add mounting holes
    [AnyFridge.brd]
2025-03-13 move resistors to top layer
    [AnyFridge.brd]
2025-03-13 Silkscreen fixes
    [AnyFridge.brd]
2025-03-13 Fix more silkscreen problems
    [AnyFridge.brd]
2025-03-18 prototype ui created
2025-03-24 almost full functionality, only missing delete button usage
2025-03-25 Updated to include sample integration testing.
2025-03-25 experimental changes for delete button functionality
2025-04-08 Add test button and test blink
2025-04-17 Fix button to INPUT_PULLDOWN
    [test_button.cpp]
2025-04-17 working delete button + nutrition information. Attempting to add fancy expiration date logic
2025-04-18 updated sleeve
    [sleeve.blend]
2025-04-19 Updated source to include NetWizard and fix barcode scanning issues
    [main.cpp]

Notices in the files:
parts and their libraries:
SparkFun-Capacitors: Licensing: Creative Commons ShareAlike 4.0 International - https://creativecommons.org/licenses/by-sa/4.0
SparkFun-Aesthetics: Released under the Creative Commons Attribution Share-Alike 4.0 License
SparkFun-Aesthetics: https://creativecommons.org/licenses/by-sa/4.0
